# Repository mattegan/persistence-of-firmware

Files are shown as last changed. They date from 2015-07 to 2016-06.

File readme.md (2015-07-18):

## persistence of firmware

Code + schematics + layout + documentation for my persistence of vision PCB business card. First revision of the board was sent to OSHPark on July 15th and is expected back on the 28th. Parts were ordered from Digikey on the 15th as well.

```
/design -- eagle board and schematic files (.brd, .sch)
    /cam -- cam files (usually not up to date with .brd file)
/documents
    /datasheets -- datasheet documents for every major component (.pdf)
    /misc -- current bom and parts order lists from Digikey
    -- various text files containing unorganized thoughts
/firmware -- MPLAB X Project file and firmware source
```

### rev0
Board uses a PIC18F2XK20, and includes a 3-axis accelerometer (LIS3DSH) and ambient light sensor (APDS-9008). The accelerometer will be used to detect the edges of the shaking motion to time out each LED column, and the light sensor will be used to program new messages into the card using a webapp that flashes the screen. The board has a on-off switch, and a switch to put it into programming mode. Further modes may be selectable from the webapp. The board is powered from two CR2032s (rev0) in parallel at 3.0V each. A boost converter (MCP1640) steps the voltage up to 3.3V.

### form factor goals
Most of the PCB business cards I've seen have been clunky, and not very likely to be put inside a wallet, so I wanted something that would be completely flush (no compoents or batteries protruding from the top or the bottom of the board).

The final card will be a stackup of two PCBs. The bottom PCB will be 0.6mm thick, and will have all of the components mounted on it (except for the light sensor and it's supporting components). The top PCB will be 1.0mm thick, and will have cutouts in the same locations as the components on the bottom board. This way the two boards will lay on top of one another and no components will protrude from the surface of the card. All components were chosen to be less than 1.0mm thick.

CR2016 batteries are exactly 1.6mm thick. Holes will be cut through both boards in the same location, and two CR2016s will be placed inside. This way, the batteries themselves will be flush with the board. Power connections will be made between the top and bottom PCB, since one side of each battery will be connected to the bottom board.

The light sensor will be placed on the bottom of the 1.0mm board, and have a corresponding hole in the 0.6mm board. This way the LEDs can be seen as progress indicators when the board is placed flat, bottom down on a display.

The first revision has none of these features. It was built as a quick proof of concept so I can work on the firmware while I'm working on the real version.

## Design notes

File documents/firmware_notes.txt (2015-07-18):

- accelerometer
  - registers that need changing
    - CTRL_REG3 (23h)
      - IEA - set interrupt polarity to active high
      - IEL - interrupt latching (? what is this ?)
    - CTRL_REG4 (20h)
      - ODR - set output data rate (? to what ?)
      - BDU - block data update (? if reading not fast enough ?)
    - CTRL_REG6 (25h)
      - FIFO_EN - FIFO buffer enable (? do I need to ?)

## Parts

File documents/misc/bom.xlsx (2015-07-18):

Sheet: rev0_parts_order
Index | Quantity | Part Number | Manufacturer Part Number | Description | Customer Reference | Backorder | Unit Price | Extended Price
1 | 40 | 846-1111-6-ND | SCMP13WBC8W1 | LED DISCRETE |  | 0 | 0.60175 | $24.07
2 | 7 | 401-2005-1-ND | JS102000SAQN | SWITCH SLIDE SPDT 1MA 5V |  | 0 | 0.64 | $4.48
3 | 4 | 516-2662-1-ND | APDS-9008-020 | IC PHOTOSENSOR AMBIENT 6CHIPLED |  | 0 | 1.23 | $4.92
4 | 100 | 1276-1114-1-ND | CL21F104ZBANNNC | CAP CER 0.1UF 50V Y5V 0805 |  | 0 | 0.0144 | $1.44
5 | 10 | 399-9563-1-ND | L0603C100KSMST | FIXED IND 10UH 5MA 2.55 OHM SMD |  | 0 | 0.227 | $2.27
6 | 50 | P10KGCT-ND | ERJ-3GEYJ103V | RES SMD 10K OHM 5% 1/10W 0603 |  | 0 | 0.0096 | $0.48
7 | 3 | 445-17130-1-ND | VLF403210MT-4R7M-CA | FIXED IND 4.7UH 1.61A 140 MOHM |  | 0 | 1.85 | $5.55
8 | 3 | PIC18F26K20-I/ML-ND | PIC18F26K20-I/ML | IC MCU 8BIT 64KB FLASH 28QFN |  | 0 | 2.92 | $8.76
9 | 25 | 1276-1096-1-ND | CL21A106KOQNNNE | CAP CER 10UF 16V 10% X5R 0805 |  | 0 | 0.1244 | $3.11
10 | 6 | 36-3002CT-ND | 3002TR | HOLDER BATTERY COIN 20MM DIA SMD |  | 0 | 0.9 | $5.40
11 | 3 | 497-13244-1-ND | LIS3DSHTR | ACCELEROMETER 3AXIS MEMS 16-LGA |  | 0 | 2.52 | $7.56
12 | 4 | 3M9476-ND | 961125-5604-AR | CONN HEADER R/A SGL 25POS GOLD |  | 0 | 1.62 | $6.48
13 | 25 | 1276-1901-1-ND | CL10A475KQ5LNNC | CAP CER 4.7UF 6.3V 10% X5R 0603 |  | 0 | 0.06 | $1.50
14 | 50 | P536KHCT-ND | ERJ-3EKF5363V | RES SMD 536K OHM 1% 1/10W 0603 |  | 0 | 0.0114 | $0.57
15 | 100 | P309KHCT-ND | ERJ-3EKF3093V | RES SMD 309K OHM 1% 1/10W 0603 |  | 0 | 0.0084 | $0.84
16 | 100 | P1.8KGCT-ND | ERJ-3GEYJ182V | RES SMD 1.8K OHM 5% 1/10W 0603 |  | 0 | 0.0071 | $0.71
 |  |  |  |  |  |  | Subtotal | $78.14

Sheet: Sheet1
Simple Description | Digikey Part # | Mfg Part # | Description | Quantity | Unit Price | Subtotal | Total
LED | 846-1111-6-ND | SCMP13WBC8W1 | LED DISCRETE | 10 | 0.60175 | 6.0175 | 19.6829
Slide Switch | 401-2005-1-ND | JS102000SAQN | SWITCH SLIDE SPDT 1MA 5V | 2 | 0.64 | 1.28
Photosensor | 516-2662-1-ND | APDS-9008-020 | IC PHOTOSENSOR AMBIENT 6CHIPLED | 1 | 1.23 | 1.23
0.1uF 0805 Cap. | 1276-1114-1-ND | CL21F104ZBANNNC | CAP CER 0.1UF 50V Y5V 0805 | 3 | 0.0144 | 0.0432
10kOhm 0603 Res. | P10KGCT-ND | ERJ-3GEYJ103V | RES SMD 10K OHM 5% 1/10W 0603 | 2 | 0.0096 | 0.0192
4.7uH Ind. | 445-17130-1-ND | VLF403210MT-4R7M-CA | FIXED IND 4.7UH 1.61A 140 MOHM | 1 | 1.85 | 1.85
PIC uC | PIC18F26K20-I/ML-ND | PIC18F26K20-I/ML | IC MCU 8BIT 64KB FLASH 28QFN | 1 | 2.92 | 2.92
10uF 0805 Cap. | 1276-1096-1-ND | CL21A106KOQNNNE | CAP CER 10UF 16V 10% X5R 0805 | 2 | 0.1244 | 0.2488
Battery Holder | 36-3002CT-ND | 3002TR | HOLDER BATTERY COIN 20MM DIA SMD | 2 | 0.9 | 1.8
Accelerometer | 497-13244-1-ND | LIS3DSHTR | ACCELEROMETER 3AXIS MEMS 16-LGA | 1 | 2.52 | 2.52
Right Angle Headers | 3M9476-ND | 961125-5604-AR | CONN HEADER R/A SGL 25POS GOLD | 1 | 1.62 | 1.62
4.7uF 0603 Cap. | 1276-1901-1-ND | CL10A475KQ5LNNC | CAP CER 4.7UF 6.3V 10% X5R 0603 | 1 | 0.06 | 0.06
536kOhm 0603 Res. | P536KHCT-ND | ERJ-3EKF5363V | RES SMD 536K OHM 1% 1/10W 0603 | 1 | 0.0114 | 0.0114
309kOhm 0603 Res. | P309KHCT-ND | ERJ-3EKF3093V | RES SMD 309K OHM 1% 1/10W 0603 | 1 | 0.0084 | 0.0084
1.8kOhm 0603 Res. | P1.8KGCT-ND | ERJ-3GEYJ182V | RES SMD 1.8K OHM 5% 1/10W 0603 | 10 | 0.00544 | 0.0544

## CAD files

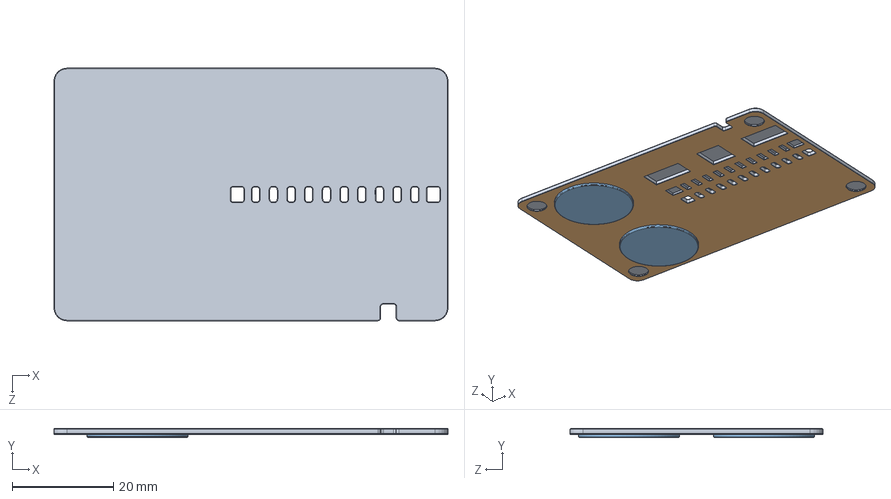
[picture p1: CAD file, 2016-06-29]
design/rev2/mechanical/card.SLDASM
78.0 x 1.74 x 50.0 mm
steel_front
kapton^card
cr2016 x 2

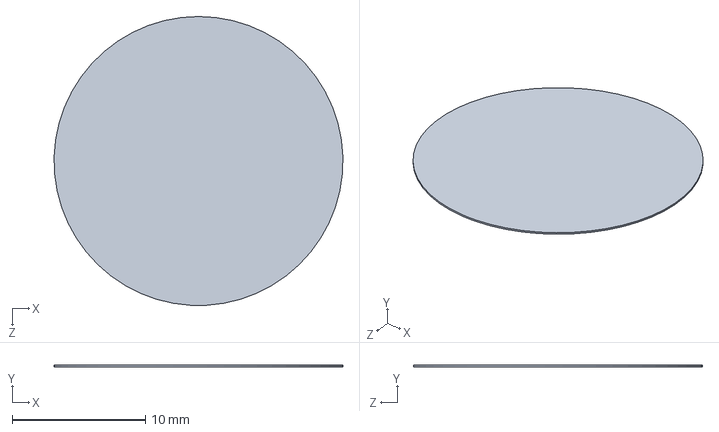
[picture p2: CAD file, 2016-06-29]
design/rev2/mechanical/battery_cap.SLDPRT
21.7 x 0.127 x 21.7 mm

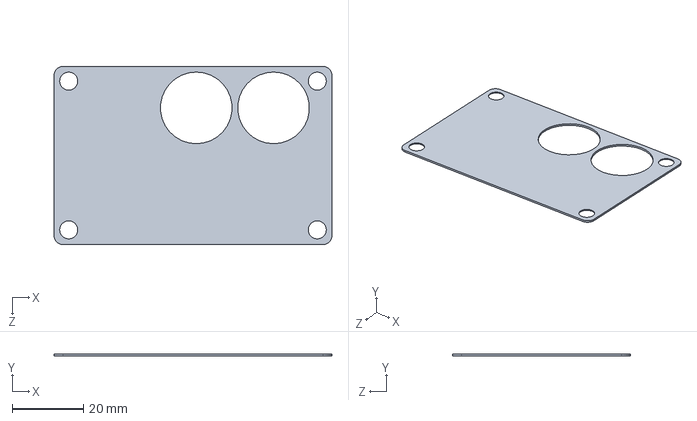
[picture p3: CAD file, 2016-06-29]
design/rev2/mechanical/pcb.SLDPRT
78.0 x 0.6 x 50.0 mm

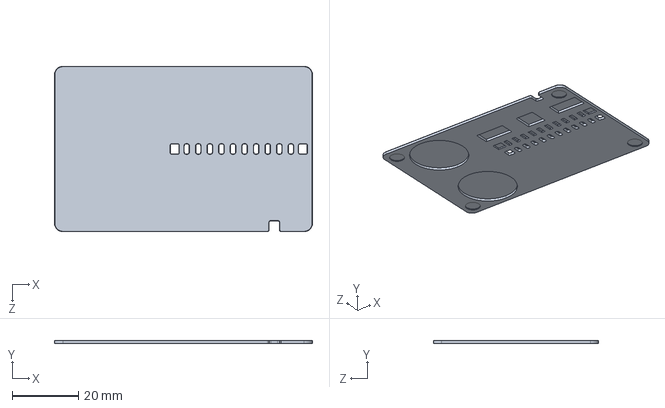
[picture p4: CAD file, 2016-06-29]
design/rev2/mechanical/steel_front.STEP
78.0 x 1.02 x 50.0 mm

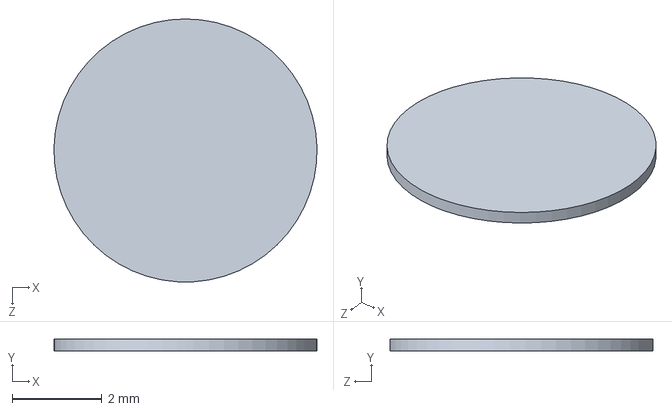
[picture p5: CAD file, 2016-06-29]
design/rev2/mechanical/steel_cap.SLDPRT
5.87 x 0.267 x 5.87 mm

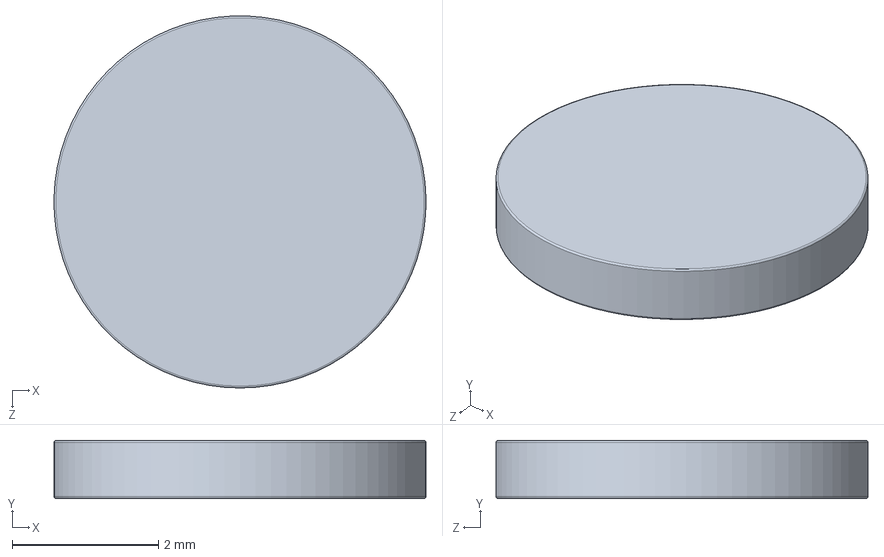
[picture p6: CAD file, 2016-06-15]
design/rev2/mechanical/magnet(d_0.2)(t_0.03125).SLDPRT
5.08 x 0.794 x 5.08 mm

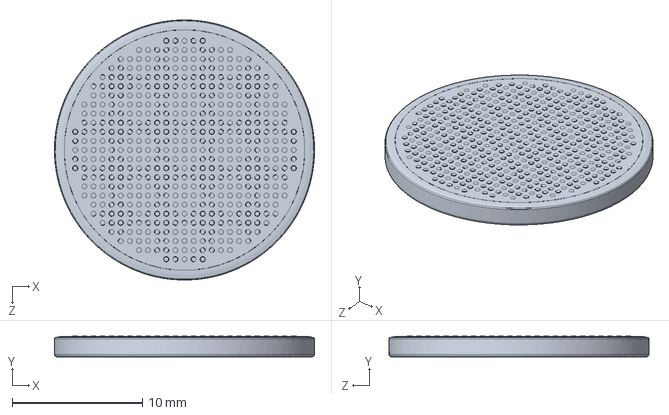
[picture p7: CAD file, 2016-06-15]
design/rev2/mechanical/cr2016.SLDPRT
20.0 x 1.60 x 20.0 mm

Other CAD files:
design/rev2/mechanical/steel_front_AP203.STEP
design/rev2/mechanical/steel_front_AP214.STEP
design/rev2/mechanical/copper_battery_cap.SLDPRT
design/rev2/mechanical/steel_front.DWG
design/rev2/mechanical/steel_front.DXF
design/rev2/mechanical/steel_front.SLDDRW
design/rev2/mechanical/steel_front.SLDPRT

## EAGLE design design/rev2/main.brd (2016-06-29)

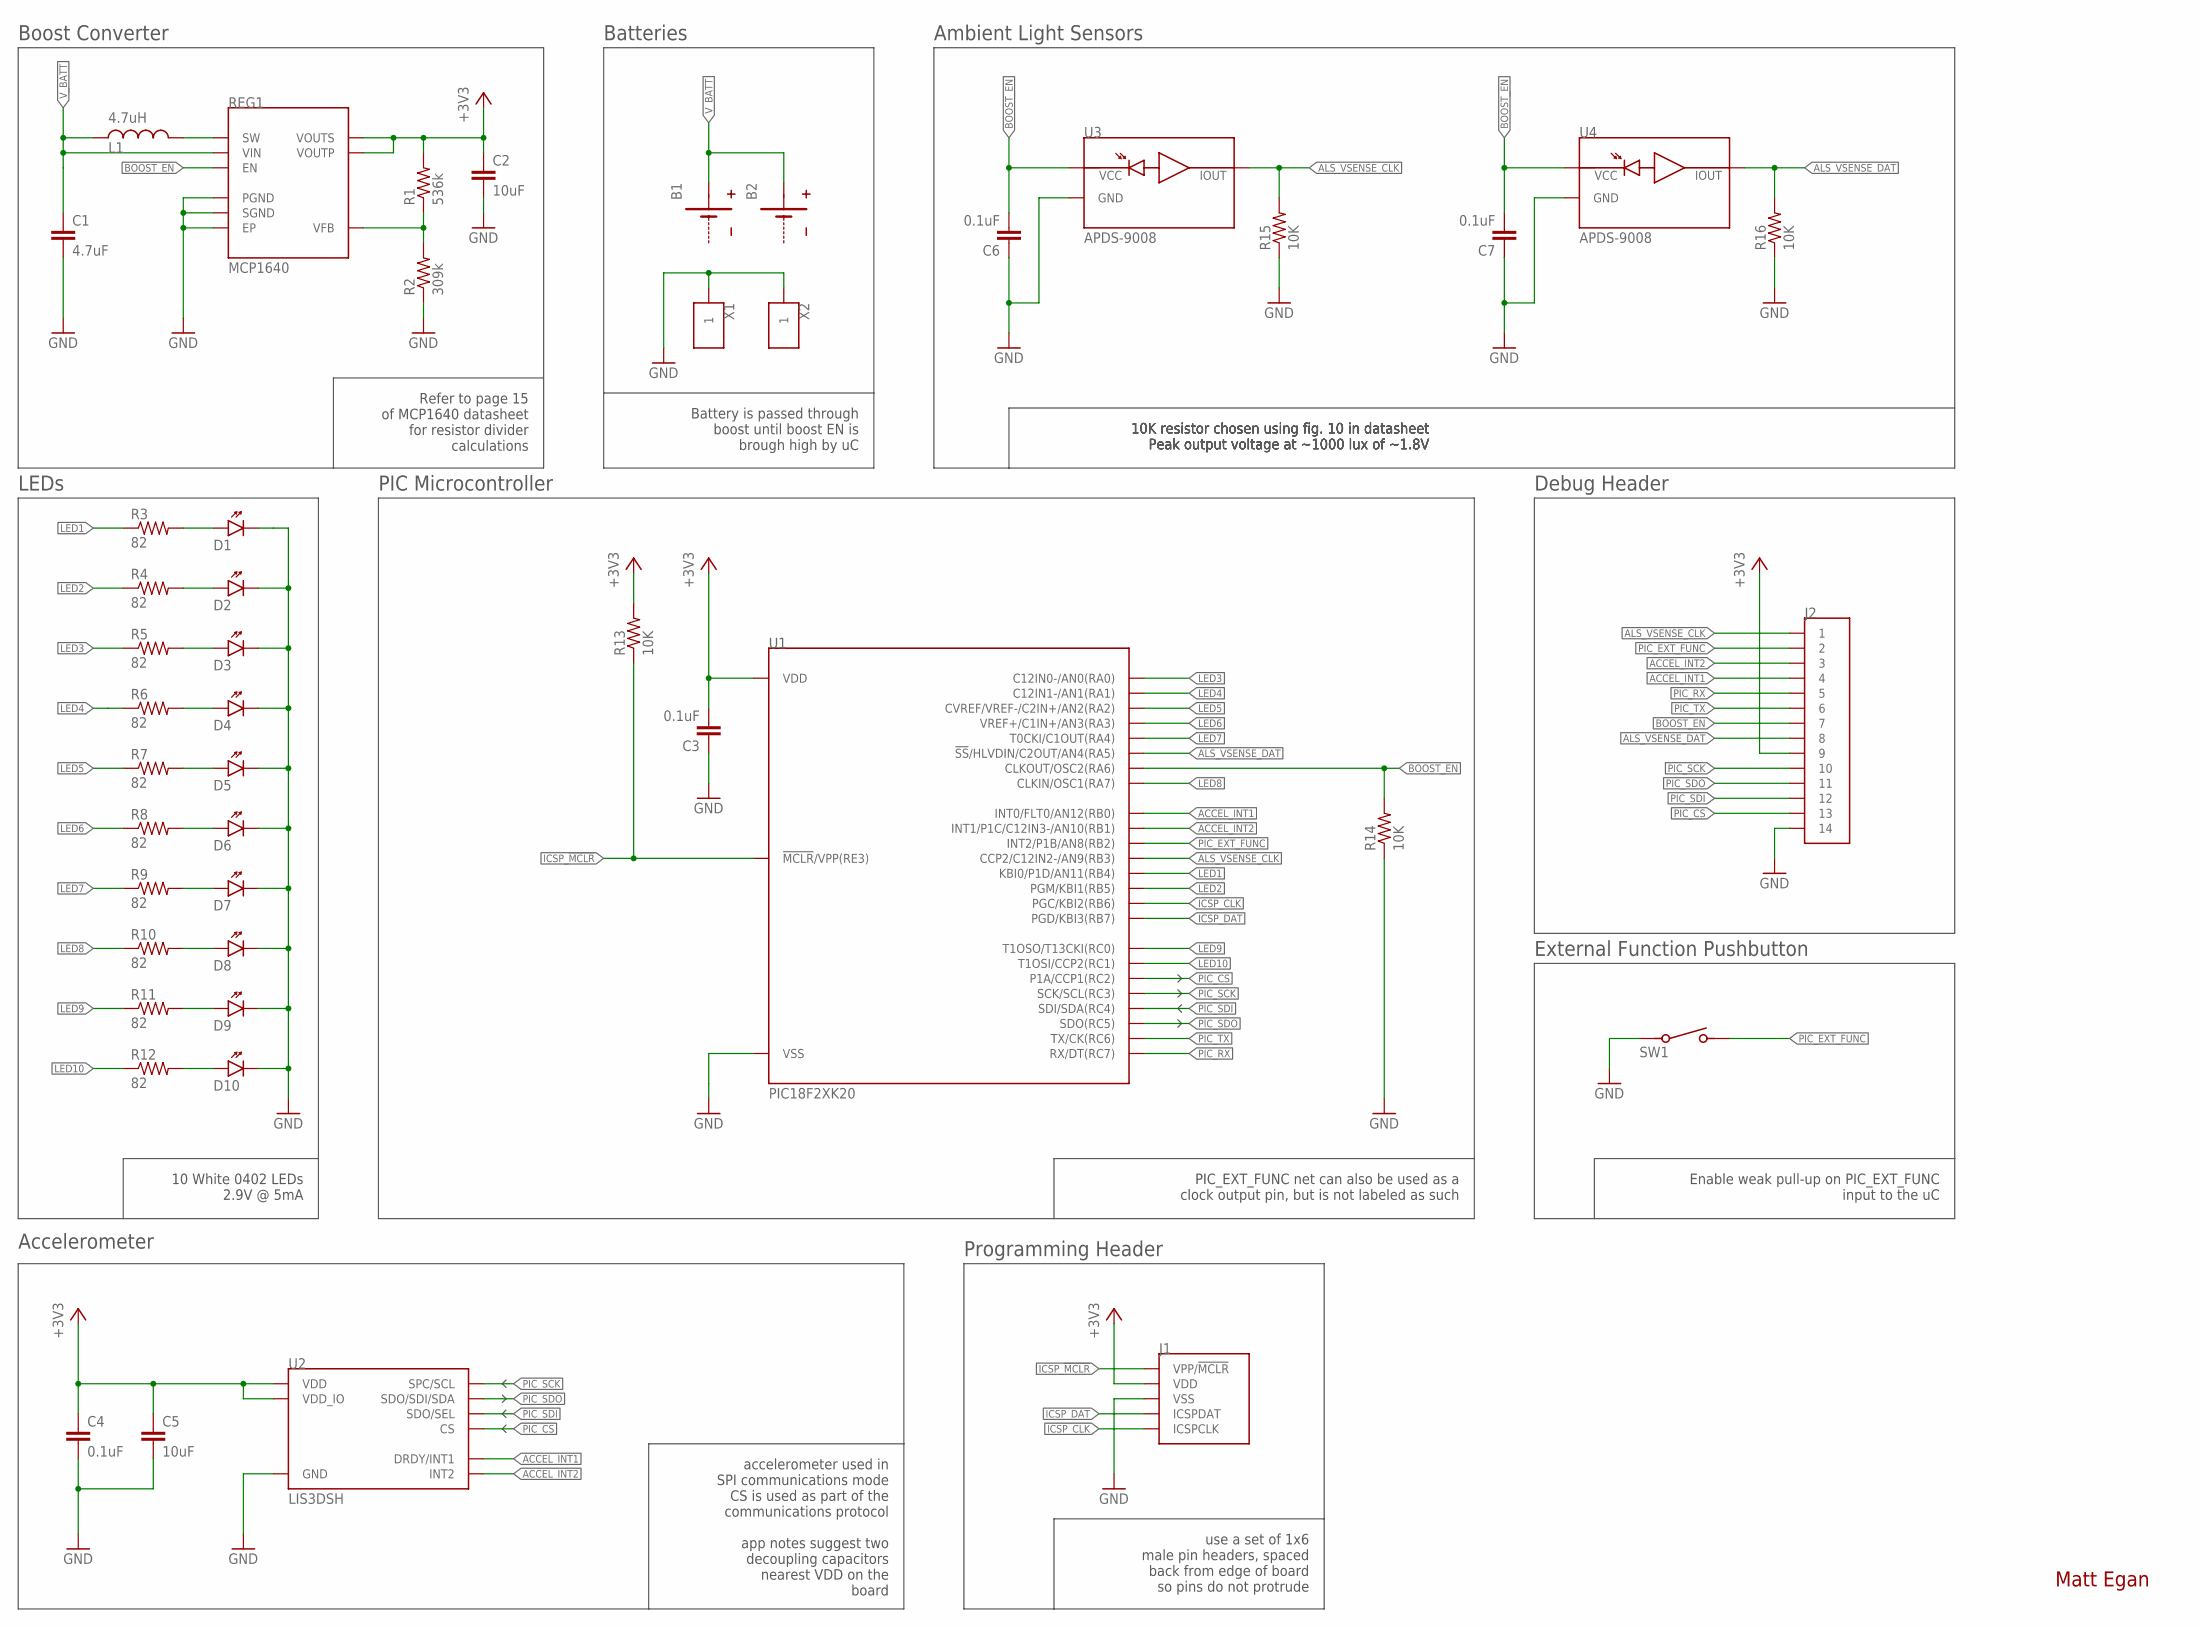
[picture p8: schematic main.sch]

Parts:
B1, B2: BATTERY-POS-HALF; CR20XX-PLATED
C1: 4.7uF; SMD-0603
C2: 10uF; SMD-0603
C3, C4, C6, C7: 0.1uF; SMD-0805
C5: 10uF; SMD-0805
D1, D2, D3, D4, D5, D6, D7, D8, D9, D10: LED0603; SMD-0603-P
J1: ICSP-HEADER1X6-0.1-ICSP-PADS; 1X6-0.1-ICSP-PADS
J2: HEADER-141X14-0.05-PADS; 1X14-0.05-PADS
L1: 4.7uH; VLF403210MT
R1: 536k; SMD-0603
R2: 309k; SMD-0603
R3, R4, R5, R6, R7, R8, R9, R10, R11, R12: 82; SMD-0603
R13, R14, R15, R16: 10K; SMD-0603
REG1: MCP1640; DFN-8(2X3)
SW1: B3U-3000P
U1: PIC18F2XK20; QFN-28
U2: LIS3DSH; LGA-16
U3, U4: APDS-9008; AVAGO-CHIPLED6
X1, X2: TE-2199248-X

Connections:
+3V3: C2.1, C3.2, C4.1, C5.1, J1.P$2 (VDD), J2.P$9 (9), R1.2, R13.2, REG1.6 (VOUTP), REG1.7 (VOUTS), U1.P$17 (VDD), U2.P$1 (VDD_IO), U2.P$14 (VDD), U2.P$15 (VDD)
ACCEL_INT1: J2.P$4 (4), U1.P$18 (INT0/FLT0/AN12(RB0)), U2.P$11 (DRDY/INT1)
ACCEL_INT2: J2.P$3 (3), U1.P$19 (INT1/P1C/C12IN3-/AN10(RB1)), U2.P$9 (INT2)
ALS_VSENSE_CLK: J2.P$1 (1), R15.2, U1.P$21 (CCP2/C12IN2-/AN9(RB3)), U3.P$6 (P$IOUT)
ALS_VSENSE_DAT: J2.P$8 (8), R16.2, U1.P$4 (!SS!/HLVDIN/C2OUT/AN4(RA5)), U4.P$6 (P$IOUT)
BOOST_EN: C6.2, C7.2, J2.P$7 (7), R14.2, REG1.4 (EN), U1.P$7 (CLKOUT/OSC2(RA6)), U3.P$1 (P$VCC), U4.P$1 (P$VCC)
GND: C1.2, C2.2, C3.1, C4.2, C5.2, C6.1, C7.1, D1.-, D2.-, D3.-, D4.-, D5.-, D6.-, D7.-, D8.-, D9.-, D10.-, J1.P$3 (VSS), J2.P$14 (14), R2.1, R14.1, R15.1, R16.1, REG1.2 (SGND), REG1.3 (PGND), REG1.EP, SW1.SW$1 (1), U1.P$5 (VSS), U1.P$16 (VSS), U2.P$5 (GND), U2.P$10 (GND), U2.P$12 (GND), U2.P$13 (GND), U2.P$16 (GND), U3.P$4 (GND), U4.P$4 (GND), X1.P$1, X1.P$2, X2.P$1, X2.P$2
ICSP_!MCLR!: J1.P$1 (VPP/!MCLR!), R13.1, U1.P$26 (!MCLR!/VPP(RE3))
ICSP_CLK: J1.P$5 (ICSPCLK), U1.P$24 (PGC/KBI2(RB6))
ICSP_DAT: J1.P$4 (ICSPDAT), U1.P$25 (PGD/KBI3(RB7))
LED1: R3.1, U1.P$22 (KBI0/P1D/AN11(RB4))
LED2: R4.1, U1.P$23 (PGM/KBI1(RB5))
LED3: R5.1, U1.P$27 (C12IN0-/AN0(RA0))
LED4: R6.1, U1.P$28 (C12IN1-/AN1(RA1))
LED5: R7.1, U1.P$1 (CVREF/VREF-/C2IN+/AN2(RA2))
LED6: R8.1, U1.P$2 (VREF+/C1IN+/AN3(RA3))
LED7: R9.1, U1.P$3 (T0CKI/C1OUT(RA4))
LED8: R10.1, U1.P$6 (CLKIN/OSC1(RA7))
LED9: R11.1, U1.P$8 (T1OSO/T13CKI(RC0))
LED10: R12.1, U1.P$9 (T1OSI/CCP2(RC1))
unnamed: L1.P$2 (2), REG1.5 (SW)
unnamed: R1.1, R2.2, REG1.1 (VFB)
unnamed: D1.+, R3.2
unnamed: D2.+, R4.2
unnamed: D3.+, R5.2
unnamed: D4.+, R6.2
unnamed: D5.+, R7.2
unnamed: D6.+, R8.2
unnamed: D7.+, R9.2
unnamed: D8.+, R10.2
unnamed: D9.+, R11.2
unnamed: D10.+, R12.2
PIC_CS: J2.P$13 (13), U1.P$10 (P1A/CCP1(RC2)), U2.P$8 (CS)
PIC_EXT_FUNC: J2.P$2 (2), SW1.SW$2 (3), U1.P$20 (INT2/P1B/AN8(RB2))
PIC_RX: J2.P$5 (5), U1.P$15 (RX/DT(RC7))
PIC_SCK: J2.P$10 (10), U1.P$11 (SCK/SCL(RC3)), U2.P$4 (SPC/SCL)
PIC_SDI: J2.P$12 (12), U1.P$12 (SDI/SDA(RC4)), U2.P$7 (SDO/SEL)
PIC_SDO: J2.P$11 (11), U1.P$13 (SDO(RC5)), U2.P$6 (SDO/SDI/SDA)
PIC_TX: J2.P$6 (6), U1.P$14 (TX/CK(RC6))
V_BATT: B1.P$1, B2.P$1, C1.1, L1.P$1 (1), REG1.8 (VIN)

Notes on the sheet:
Matt Egan
Accelerometer
Refer to page 15 of MCP1640 datasheet for resistor divider calculations
Boost Converter
Batteries
LEDs
10 White 0402 LEDs 2.9V @ 5mA
Programming Header
Ambient Light Sensors
10K resistor chosen using fig. 10 in datasheet Peak output voltage at ~1000 lux of ~1.8V
use a set of 1x6 male pin headers, spaced back from edge of board so pins do not protrude
Debug Header
PIC Microcontroller
accelerometer used in SPI communications mode CS is used as part of the communications protocol app notes suggest two decoupling capacitors nearest VDD on the board
External Function Pushbutton
PIC_EXT_FUNC net can also be used as a clock output pin, but is not labeled as such
Battery is passed through boost until boost EN is brough high by uC
Enable weak pull-up on PIC_EXT_FUNC input to the uC

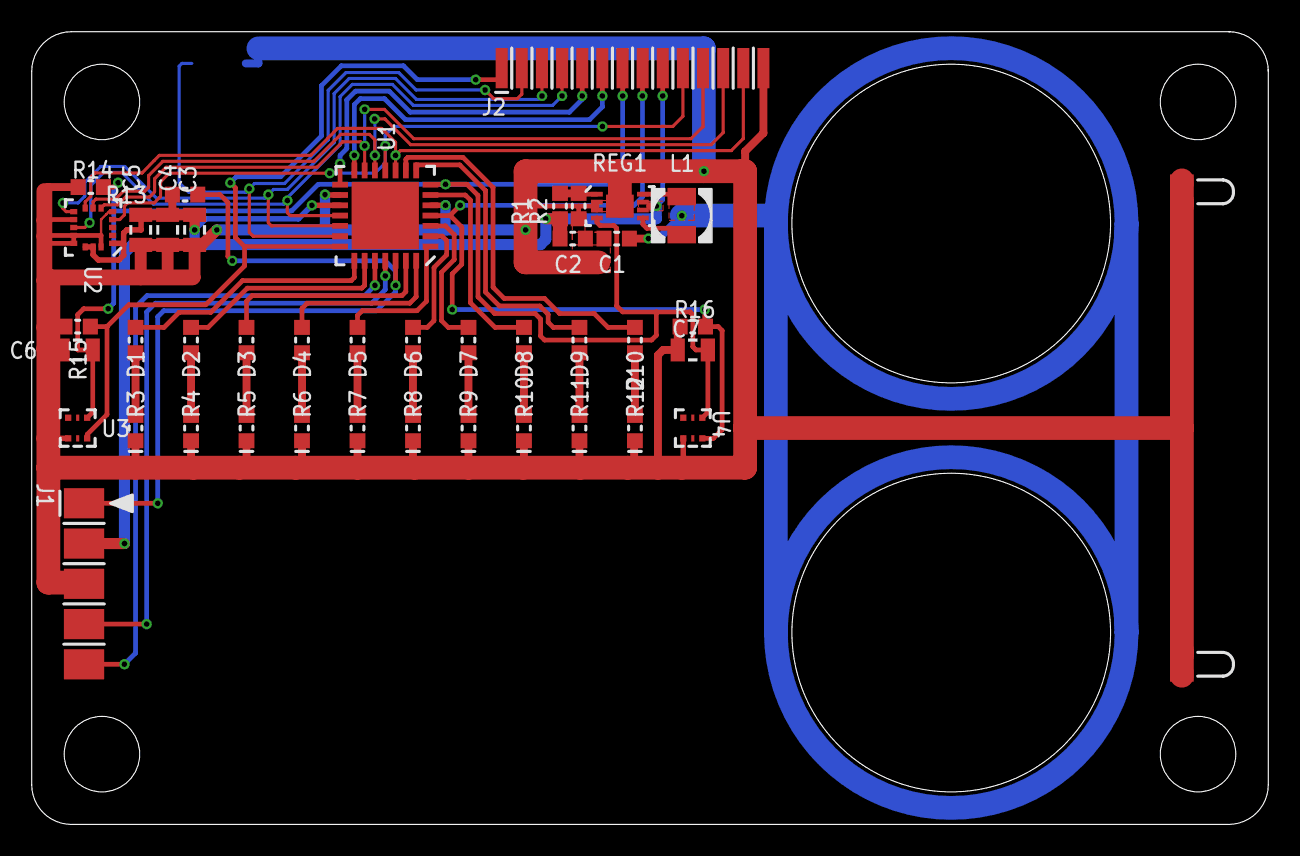
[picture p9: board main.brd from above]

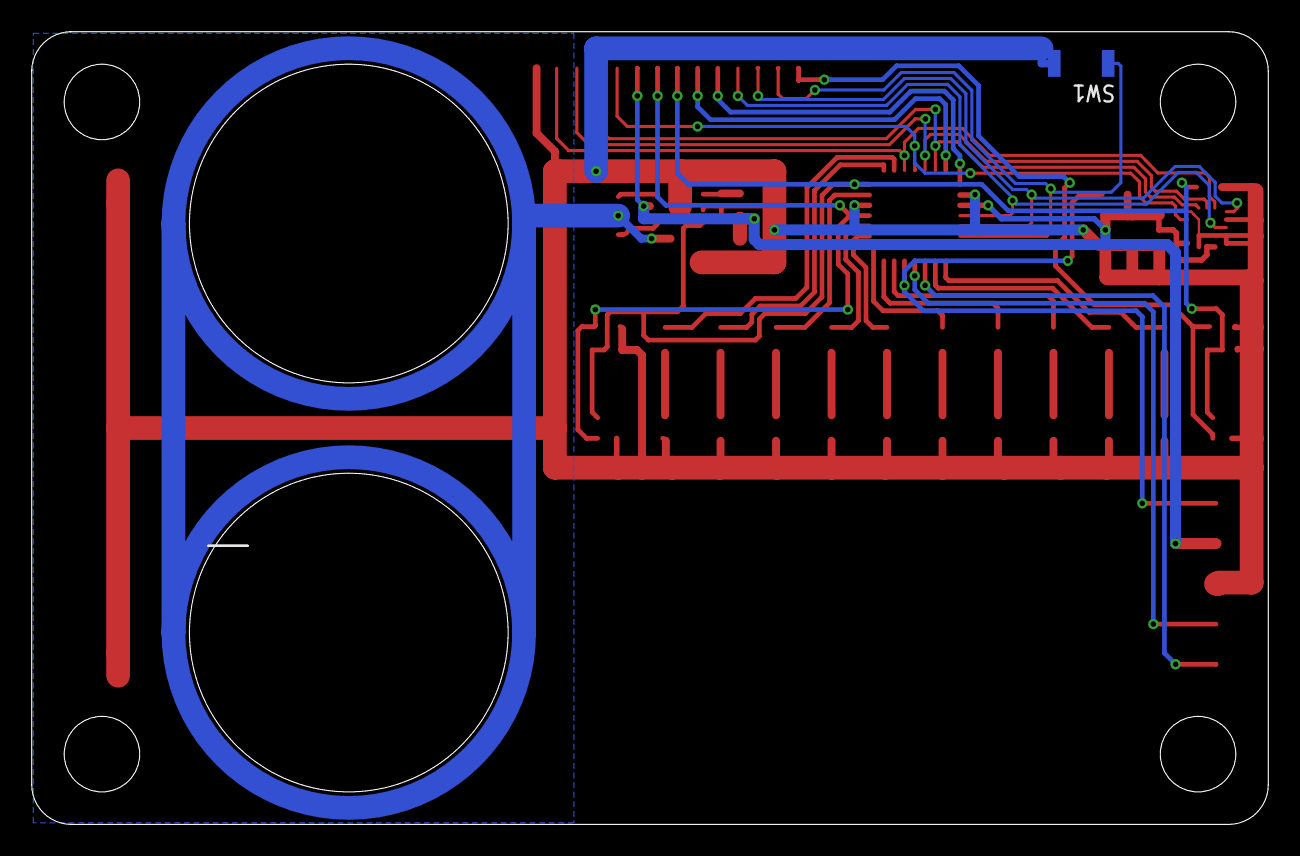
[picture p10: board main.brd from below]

Board: 2 copper layers, 78.0 x 50.0 mm, 46 parts (3 on the bottom side), 40 nets.

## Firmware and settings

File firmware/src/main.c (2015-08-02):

#include <stdio.h>
#include <stdlib.h>
#include <xc.h>
#include <limits.h>

////////////////////////////////////////////////////////////////////////////////
// Project Level Includes
////////////////////////////////////////////////////////////////////////////////
#include "config.h"

void setLEDOutput(unsigned int flag);

void setup();
void setupClock();
void setupLEDs();
void setupSPI();
void setupAccelerometer();
void setupUART();

void SPIRead(unsigned char addr, int length, unsigned char *out);
void SPIWrite(unsigned char addr, int length, unsigned char *in);
void UARTPutC(unsigned char data);
void UARTPutStr(unsigned const char *str); //null terminated
char*intToStr(int num);

signed int getYAcceleration();

static unsigned long periodCount = 0;
static unsigned int periodCountOverflow = 0;

static unsigned int columnTimerPeriod;
static unsigned int columnTimerCount = 0;

static unsigned int posPeak = 1;
#define THRESHOLD 19000

static unsigned int currentColumn = 0;
static unsigned int columnCount = 69;
static unsigned int image[69] = {
    0b0000000000,
    0b0000000000,
    0b0000000000,
    0b0000000000,
    0b0000000000,
    0b0000000000,
    0b0000000000,
    0b0000000000,
    0b0001111111,
    0b0000000010,
    0b0000001100,
    0b0000000010,
    0b0001111111,
    0b0000000000,
    0b0000100000,
    0b0001010100,
    0b0001010100,
    0b0001010100,
    0b0001111000,
    0b0000000000,
    0b0000000100,
    0b0000111110,
    0b0001000100,
    0b0001000000,
    0b0000100000,
    0b0000000000,
    0b0000000100,
    0b0000111110,
    0b0001000100,
    0b0001000000,
    0b0000100000,
    0b0000000000,
    0b0000000000,
    0b0000000000,
    0b0000000000,
    0b0000000000,
    0b0000000000,
    0b0000000000,
    0b0001111111,
    0b0001001001,
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
};

int main(int argc, char** argv) {

    setup();

    //enable interrupts
    INTCONbits.GIE = 1;     //enable global interrupts
    INTCONbits.PEIE = 1;    //enable peripheral interrupts

    //setup timer 0, which times the length of one shake
    T0CONbits.T0CS = 0;     //timer 0 is driven by Fosc/4
    T0CONbits.PSA = 0;      //enable timer 0 clock prescaler

    T0CONbits.TMR0ON = 1;   //turn timer 0 on
    T0CONbits.T0PS = 0b010; //1:8 prescale value for timer 0;

    //INFO : timer 0 will overflow at 7.813KHz, meaning that one overflow of periodCount is equal to
    //       128us
    INTCONbits.TMR0IE = 1;  //enable timer 0 overflow interrupts

    //setup timer 1, which times out each column of the display
    T1CONbits.TMR1ON = 1;   //turn on timer 1
    TMR1H = 0xF0;           //set the count to 15/16ths of the overflow value
    TMR1L = 0x00;

    //INFO : since timer 1 is configured with a prescaler of 1:1, and Fosc/4 = 16MHz, it will
    //       overflow (16bits) at 244.1Hz, with a period of 4.096ms, to cause the overflow to occur
    //       faster, the counter register is preloaded with 0xF000 at every overflow, which is
    //       15/16ths the overflow value of 0xFFFF, so the counter (running at 16Mhz) only has to
    //       count 0xFFF more to overflow, this will happen at 7.637kHz, or every 130.9us, this is
    //       chosen so that if there are about 3 shakes in a second, the timer can still keep track
    //       of line widths of 100 or more


    signed int y;
    signed int previousY = getYAcceleration();
    float shakePeriod;
    float columnPeriod;

    while(1) {

        //get the current y acceleration
        y = getYAcceleration();

        //need to do a peak find, alternating between "peaks" and "troughs"
        //alternating between searching for these get us the left and right
        //edges of the shake
        if(posPeak && y < previousY || !posPeak && y > previousY) {
            if(posPeak && (y > THRESHOLD) || !posPeak && y < -THRESHOLD) {
                //a peak was found, now we need to search for the opposite peak
                posPeak = !posPeak;

                //now we need to setup timer 1 to generate `rowCount` pulses during one shake
                shakePeriod = periodCount * 128.0e-6;
                columnPeriod = shakePeriod/((float)columnCount);
                columnTimerPeriod = (int)(columnPeriod/(256.0e-6));

                //enable TMR1 interrupts
                PIE1bits.TMR1IE = 1;

                //start a new period
                periodCount = 0;
                columnTimerCount = 0;
                currentColumn = 0;
            }
        }
        previousY = y;
    }
}

void interrupt isr(void) {
    if(INTCONbits.TMR0IF) {
        //this timer increments a period timer so we can count how long the last shake took
        periodCount++;
        INTCONbits.TMR0IF = 0;
    }
    if(PIR1bits.TMR1IF) {
        TMR1H = 0xF0;
        TMR1L = 0x00;
        if(columnTimerCount >= columnTimerPeriod) {
            currentColumn++;
            if(currentColumn > columnCount) {
                setLEDOutput(0b0000000000);
            } else {
                if(posPeak) {
                    setLEDOutput(image[columnCount - currentColumn - 1]);
                } else {
                    setLEDOutput(image[currentColumn]);
                }
            }
            columnTimerCount = 0;
        } else {
            columnTimerCount++;
        }
        PIR1bits.TMR1IF = 0;
    }
}

////////////////////////////////////////////////////////////////////////////////////////////////////
// Setup Code
////////////////////////////////////////////////////////////////////////////////////////////////////

// top level setup, calls all other setup functions in the correct order
void setup() {
    setupClock();
    setupLEDs();
    setupSPI();
    setupAccelerometer();
    setupUART();
}

// Configures the internal oscillator to output 64MHz
void setupClock() {
    OSCCONbits.IRCF = 0b111;    //make internal oscillator run at 16MHz
    OSCTUNEbits.PLLEN = 1;      //enable the x4 PLL, only possible since FOSC is set to 0b1001 (9)
                                //and IRCF is configured to 16MHz
}

//sets all LEDs as output pins
void setupLEDs() {
    TRISBbits.TRISB4 = 0;
    TRISBbits.TRISB5 = 0;
    TRISAbits.TRISA0 = 0;
    TRISAbits.TRISA1 = 0;
    TRISAbits.TRISA2 = 0;
    TRISAbits.TRISA3 = 0;
    TRISAbits.TRISA4 = 0;
    TRISAbits.TRISA7 = 0;
    TRISCbits.TRISC0 = 0;
    TRISCbits.TRISC1 = 0;
}

// Configures SPI for communication with the accelerometer
void setupSPI() {

    //configure SPI pins
    TRISCbits.TRISC2 = 0;       //set CS as an output
    TRISCbits.TRISC3 = 0;       //set SCK as an output
    TRISCbits.TRISC5 = 0;       //set SDO as an output

    //bring CS high
    LATCbits.LATC2 = 1;

    //configure the MSSP module
    SSPSTATbits.SMP = 0;        //sample input data at middle of output data time
    SSPSTATbits.CKE = 0;        //data changes on clock transition idle -> active
    SSPCON1bits.CKP = 1;        //idle state for clock is a high level
    SSPCON1bits.SSPM = 0b0001;  //SPI master mode, clock = Fosc/16 (64MHz/16 = 4MHz)
    SSPCON1bits.SSPEN = 1;      //enable serial port
}

void setLEDOutput(unsigned int flag) {
    LATBbits.LATB4 = (flag >> 0) & 1;
    LATBbits.LATB5 = (flag >> 1) & 1;
    LATAbits.LATA0 = (flag >> 2) & 1;
    LATAbits.LATA1 = (flag >> 3) & 1;
    LATAbits.LATA2 = (flag >> 4) & 1;
    LATAbits.LATA3 = (flag >> 5) & 1;
    LATAbits.LATA4 = (flag >> 6) & 1;
    LATAbits.LATA7 = (flag >> 7) & 1;
    LATCbits.LATC0 = (flag >> 8) & 1;
    LATCbits.LATC1 = (flag >> 9) & 1;
}

void setupAccelerometer() {
    unsigned char data[2] = {
        0b01100111,     //data rate -> 100Hz (ODR = 0b0110)
                        //block update -> continuous (BDU -> 0b1)
                        //axis enable -> X, Y, Z enabled
        0b00100000      //AA filter bandwidth -> 800Hz (BW -> 0b00)
                        //scale selection -> +-16Oh G (FSCALE -> 0b011);
                        //self test disabled (ST -> 0b00)
                        //SPI mode -> 4 wire mode (SIM -> 0);
    };
    SPIWrite(0x20, 1, &data[0]);
    SPIWrite(0x24, 1, &data[1]);
}

void setupUART() {
    //set the baud rate to 115.2k, using Fosc = 64MHz, the value for SPBRG is
    //taken from the datasheet
    SPBRG = 8;
    SPBRGH = 0;

    //configure the TX and RX pins as outputs (the EUSART will reconfigure them
    //automatically
    TRISCbits.TRISC6 = 1;
    TRISCbits.TRISC7 = 1;

    //configure the EUSART in async mode
    TXSTAbits.SYNC = 0;

    //enable the serial port, and enable transmission
    RCSTAbits.SPEN = 1;
    TXSTAbits.TXEN = 1;
}

void SPIRead(unsigned char addr, int length, unsigned char *out) {
    //bring CS low to begin the cycle
    LATCbits.LATC2 = 0;

    //load and tx the address into the SPI output buffer, with the read flag set
    //[7] is the R/W bit (1 -> read), and [6:0] are the address bits
    SSPBUF = addr | 0b10000000;
    while(!SSPSTATbits.BF);

    for(int i = 0; i < length; i++) {
        //write out dummy data to clock the device
        SSPBUF = 0xFF;
        while(!SSPSTATbits.BF);
        out[i] = SSPBUF;
    }
    //bring CS high to end the cycle
    LATCbits.LATC2 = 1;
}

void SPIWrite(unsigned char addr, int length, unsigned char *in) {
    //bring CS low to begin the cycle
    LATCbits.LATC2 = 0;

    //load the address into the SPI output buffer, with the write flag set
    //[7] is the write bit (0 -> write), and [6:0] are the address bits
    //chop off the 7th bit of the address if it was set for some reason
    SSPBUF = addr & 0b01111111;
    while(!SSPSTATbits.BF);

    for(int i = 0; i < length; i++) {
        SSPBUF = in[i];
        while(!SSPSTATbits.BF);
    }

    LATCbits.LATC2 = 1;
}

void UARTPutC(unsigned char data) {
    TXREG = data;
    while(!TXSTAbits.TRMT);
}

void UARTPutStr(unsigned const char *data) {
    while(*data != '\0') {
        UARTPutC(*data);
        *data++;
    }
}

char *intToStr(int num) {
    static char out[7]; //INT_MIN = -32768, so we'll need at maximum 6
                        //chars and a null termination to represent an integer
    char digits[6];     //a place to store the digits
    int digitIndex = 0; //keep track of where in the digits array we're placing
                        //digits

    int offset = 0;
    if(num < 0) {
        out[offset++] = '-';
        num = num * -1;
    }

    do {
        digits[digitIndex++] = (num % 10) + '0';
        num /= 10;
    } while(num);

    for(int i = 0; i < digitIndex + offset; i++) {
        out[i + offset] = digits[digitIndex - i - 1];
    }
    out[digitIndex + offset] = '\0';
    return out;
}

signed int getYAcceleration() {
    unsigned char yData[2];

    //TODO : optimize this to use the automatic address increment feature
    //       of the accelerometer's SPI interface
    SPIRead(0x2B, 1, &yData[0]);    //read the MSB 8 bits of the Y axis
    SPIRead(0x2A, 1, &yData[1]);    //read the LSB 8 bits of the Y axis

    return (yData[0] << 8) | yData[1];
}

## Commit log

2015-07-18 Initial Commit
    rev0 board completed, MPLAB X project initialized
    [bom.xlsx, main.brd, main.sch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]
2015-08-02 [CNG] - implemented basic functionality
    - SPI working, communicating with Accelerometer
    - UART working to communicate with a USB-UART bridge
    - implements peak detection, the LEDs (should) come on at the edge of
    each shake direction
2015-08-02 [CNG] - update comments, fix tabs
    [main.c]
2015-09-05 [CNG] - duplicated designs to rev1 folder, implemented updates, initial rev1 layout
    [main.brd, main.sch]
2016-05-26 [CNG] - more schematic and layout progress on rev1
    [main.brd, main.sch]
2016-05-27 [CNG] - finished most of the new electrical changes for rev1 (see planning.txt), starting layout
    [main.brd, main.sch]
2016-06-15 [add] - rev2, mechanical drawings of PCB and supporting elements
    Copied rev1 as rev2 to make significant changes, still may go with rev1
    design changes. Started mocking up all elements of the card in
    solidworks as it's getting more complicated.
    [battery_cap.SLDPRT, card.SLDASM, copper_battery_cap.SLDPRT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]
2016-06-29 [CNG] - finished most routing on rev2, added new mechanical drawings (not up to date with POR)
    [battery_cap.SLDPRT, card.SLDASM, kapton_insulation.SLDPRT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]
